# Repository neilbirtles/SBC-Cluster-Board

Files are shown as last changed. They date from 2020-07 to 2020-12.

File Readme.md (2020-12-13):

# SBC Cluster Board

## Overview

From many years of building Single Board Computer (SBC) Clusters and the pain to all the cables and configuration that goes with it came the idea to make a cluster board that didn't need lots of cables or a separate network switch to make it function. The SBC Cluster (SBC&#178;) Board is the embodiment of that idea.

The SBC&#178;Board will allow 5 SBC to be powered and networked over their USB-C connection. The SBC&#178; can provide up to 3.2A per port, with adjustable current limits to help limit damage in the event of any failures on the SBC themselves. Networking is provided through the use of USB gadget mode ethernet drivers that are standard in most Linux kernels.

Optional monitoring of the state of the SBC&#178; is achieved over an I2C connection to a host device. Configuration of the board is also possible over this link. A web frontend has been developed to make this a simple process without having to send arcane commands to specific registers on the I2C devices on the SBC&#178;.

The slots for SBC have been spaced so that a single 120mm fan can cool them all removing the noise of 5 smaller fans. The SBC&#178; provides a 12V step-up converter to power the fans from the proper voltage to ensure efficient cooling without the need for a second power supply.

A single 5v 100W power supply (e.g. LRS-100-5) is all that is needed to comfortably run 5 SBC meaning that the only cables required for the complete cluster are 1 mains cable to the power supply, 2 wires for +5v and 0V DC to the SBC&#178; and an optional 3 way cable to provide I2C comms back to a host device.

## SBC&#178; Components

There are a number of folders in this repository for the different components that make up the SBC&#178;. They are as follows:

##### PCB

This folder contains all the design files for the PCB, along with manufacturing information

##### Firmware

This folder contains the firmware that is flashed to the two microcontrollers that provide the control and monitoring functionality on the SBC&#178;

##### Frontend

This folder contains a Flask and Bootstrap based web frontend that can be run on one of the SBC in the cluster to provide information about and control over the SBC&#178;

##### Cases and Accessories

This folder contains the designs for the cases and accessories related to the SBC&#178;.

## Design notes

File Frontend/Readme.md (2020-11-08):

# Web Based Frontend for the SBC Cluster

This software is a Flask / Bootstrap based webserver that interfaces with the SBC Cluster board and provides easy access to allow monitoring and control of the cluster board.

This initial version provides monitoring of the supply voltage, current consumption and power for each of the slave boards and the ability to power cycle them. The ability to update the firmware in the cluster board is also provided. Future releases will provide the ability to set current limits for each SBC.

## Setup and Installation 

WiringPi-Python is required for communications with the hub board - for Khadas boards this can be installed by following the instructions here for Python 3 - https://github.com/khadas/WiringPi-Python#manual-build. Note that to get this working with Python 3 the pre-requisites required are as follows - sudo apt install python3-dev python3-setuptools swig

Setup the virtual environment to run this in with - the --system-site-packages allows access to WiringPi-Python 

`python3 -m venv venv --system-site-packages` 

Activate the virtual environment

`source venv/bin/activate`

Then install the required packages

`pip install -r requirements.txt`

Then run the webserver with

`python sbcclusterfrontend.py`

The webserver can then be accessed from the web browser of any machine on the same network at the IP address of the machine on port 5000, i.e. 192.0.0.2:5000

## Modifications for alternative SBC

The code as it stands will try and communicate with the USB hub board over the default device. On a Khadas VIM3 board this is '/dev/i2c-3' in the Khadas WiringPi-Python build, this will likely be different on different SBC. To change to a different device, e.g. '/dev/i2c-4', then change the two default setup lines `wiringpi.wiringPiI2CSetup(0x10)` and `wiringpi.wiringPiI2CSetup(0x11)` to `wiringpi.wiringPiI2CSetupInterface("/dev/i2c-4",0x10)` and `wiringpi.wiringPiI2CSetupInterface("/dev/i2c-4",0x10)` respectively. These changes need to be made in hubInterface.py

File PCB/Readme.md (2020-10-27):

# PCB Information

This is the PCB for the 5 way SBC Cluster Board. It has been produced in Eagle PCB.

## Manufacture Information

The PCBs have all been made by JLCPCB (https://jlcpcb.com/). The boards are 4 layer and must be made using controlled impedance due to the USB differential traces. The boards must be made 1.6mm thick and with the JLC controlled impedance process JLC7628

## Board Configuration

### Mains Power Measurement

There is provision on the board to use a current sensor IC to determine mains power usage for the system - this feature is mainly aimed at use in crypto currency applications where it is useful to know power consumption for the system to allow profitability to be calculated. If this function is not required then Resistor R44 is fitted to signal to the microcontroller that this function is not present on the board and J10, J11, IC7, C21 and C24 are not fitted.

### 12V DC Step-Up

The board also provides the ability to step up the incoming 5V supply to 12V to allow a standard PC fan to be powered without needing an additional power supply. The fan is connected via J8 and is the standard PC fan pinout. There is no speed control of the fan provided. If this is not required then components J8, D1, D2, C22, C23, R38, R39, IC8 and L1 are not fitted.

### Notes

IC5 can not be socketed otherwise it will foul the SBC plugged into J4. It must therefore be programmed and then soldered in

JP2 and JP3 are the programming headers for the microcontrollers on the board - they do not have to be fitted if pogo pins or similar are used to make contact for programming. Note that these headers are also used in the initial calibration (see firmware information) but the pads can be easily held low without the header fitted. 

JP4 provides the I2C bus out from the board and is set up to be a 3.3v bus with the relevant pull up resistors fitted to the board at R17 and R18 - these can be left off if the interfacing device already has pull up resistors in place. The pin-out for this is indicated on the PCB silk screen as 0-D-C for 0v, Data and Clock.

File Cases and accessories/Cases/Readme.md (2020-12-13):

# Cases

## Overview

To get the best cooling and easiest maintenance (especially prevention of dust build up) its a good idea to have a decent case for any cluster.

This folder contains the designs for cases that can be ordered from Protocase and will open in their free Protocase Designer software if you want to edit them.

## Cases

### 5 Way SBC Cluster Board Case.pda

This file contains the design for the 5 way case that is for sale on sbc-cluster.com. The case is designed to accommodate any standard 120mm fan at the rear and a 120mm dust filter at the front.

The case has mounting holes for a Meanwell LRS-75-5 power supply and an earth stud on each side of the case for safe earthing.

There is a hole cut for a snap in Bulgin Fused IEC connector for mains power inlet. The hole is sized for Bulgin part number PF0011/15/63.

Finally there is a mounting for a 5mm LED panel mount - Keystone part number 8310 will fit

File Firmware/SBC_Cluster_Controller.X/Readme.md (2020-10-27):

# SBC Cluster Controller Firmware

This firmware is used on the 5 port SBC Cluster Board. The same firmware is burnt to both the microcontrollers on the board, with configuration being set via pin strapping on the PCB.

The firmware is written in the MPLAB X IDE and uses the XC8 compiler

## Calibration

To use the voltage monitoring circuit the system must be calibrated against a known supply voltage. Once the firmware has been burnt to the microcontrollers then the calibration mode is entered by holding RB7 (pin 14) or Pin 4 of the programming header low at power on. The LED on the board will flash on /off every 100ms to indicate that it is ready for calibration, and the pin no longer has to be held low. The power supply can then be adjusted to exactly 5v. Once this has been done then the calibration is executed by taking RB6 (pin 13) or Pin 5 of the programming header low. The LED will flash 3 times at 500ms intervals to show that calibration is complete. This is a one time operation with the result stored in the non volatile memory of the microcontroller.

## Set offset for bootloader

This firmware is set up to be used with the I2C bootloader here https://github.com/neilbirtles/PIC16F1827_I2C_Bootloader. This allows for easy updating of controller firmware without a specific programmer. The project properties have been updated to start the cluster board firmware at an offset of 0x300. To use without the bootloader or with a different bootloader / offset then this can be change in Project Properties | XC8 Linker | Additional Options (in option categories) | Codeoffset 

## Memory Model Setup 

The linker will also tend to put a big gap in the middle of program memory starting at ~0x800 with some random RETLW instructions that aren't generated anywhere from the code around that address (they don't appear in the disassembly for instance, and can change the number of them with different code offset to move actual code closer / further from 0x800). Could not figure out what drove this behaviour in the linker but presumably something around management of memory pages, but it causes a problem for the bootloader because that tries to use the last address (0xFFF) in the controllers for its flag to show that a program is loaded and ready to run. The linkers approach puts program code over this location. The solution is to add the following "default,-FDF-FFF" in Project Properties | XC8 Linker | Memory Model (in option categories) | ROM Ranges. This stops the linker using the last 32 words of program memory. 32 words as PIC program memory can only be erased in complete rows (32 words for PIC16F1827), and so having this whole row blank makes for easier update (no read row, save state, erase row, change 0xFFF to the default 0x3FFF then re-write whole row, can just erase the row instead)

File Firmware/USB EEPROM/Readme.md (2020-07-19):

This is the bin file that needs to be burnt to the EEPROM that is used to configure the 2514 USB hub chip

The configuration can be viewed through the Microship Utility here:
http://ww1.microchip.com/downloads/en/DeviceDoc/e2promapp1020.msi

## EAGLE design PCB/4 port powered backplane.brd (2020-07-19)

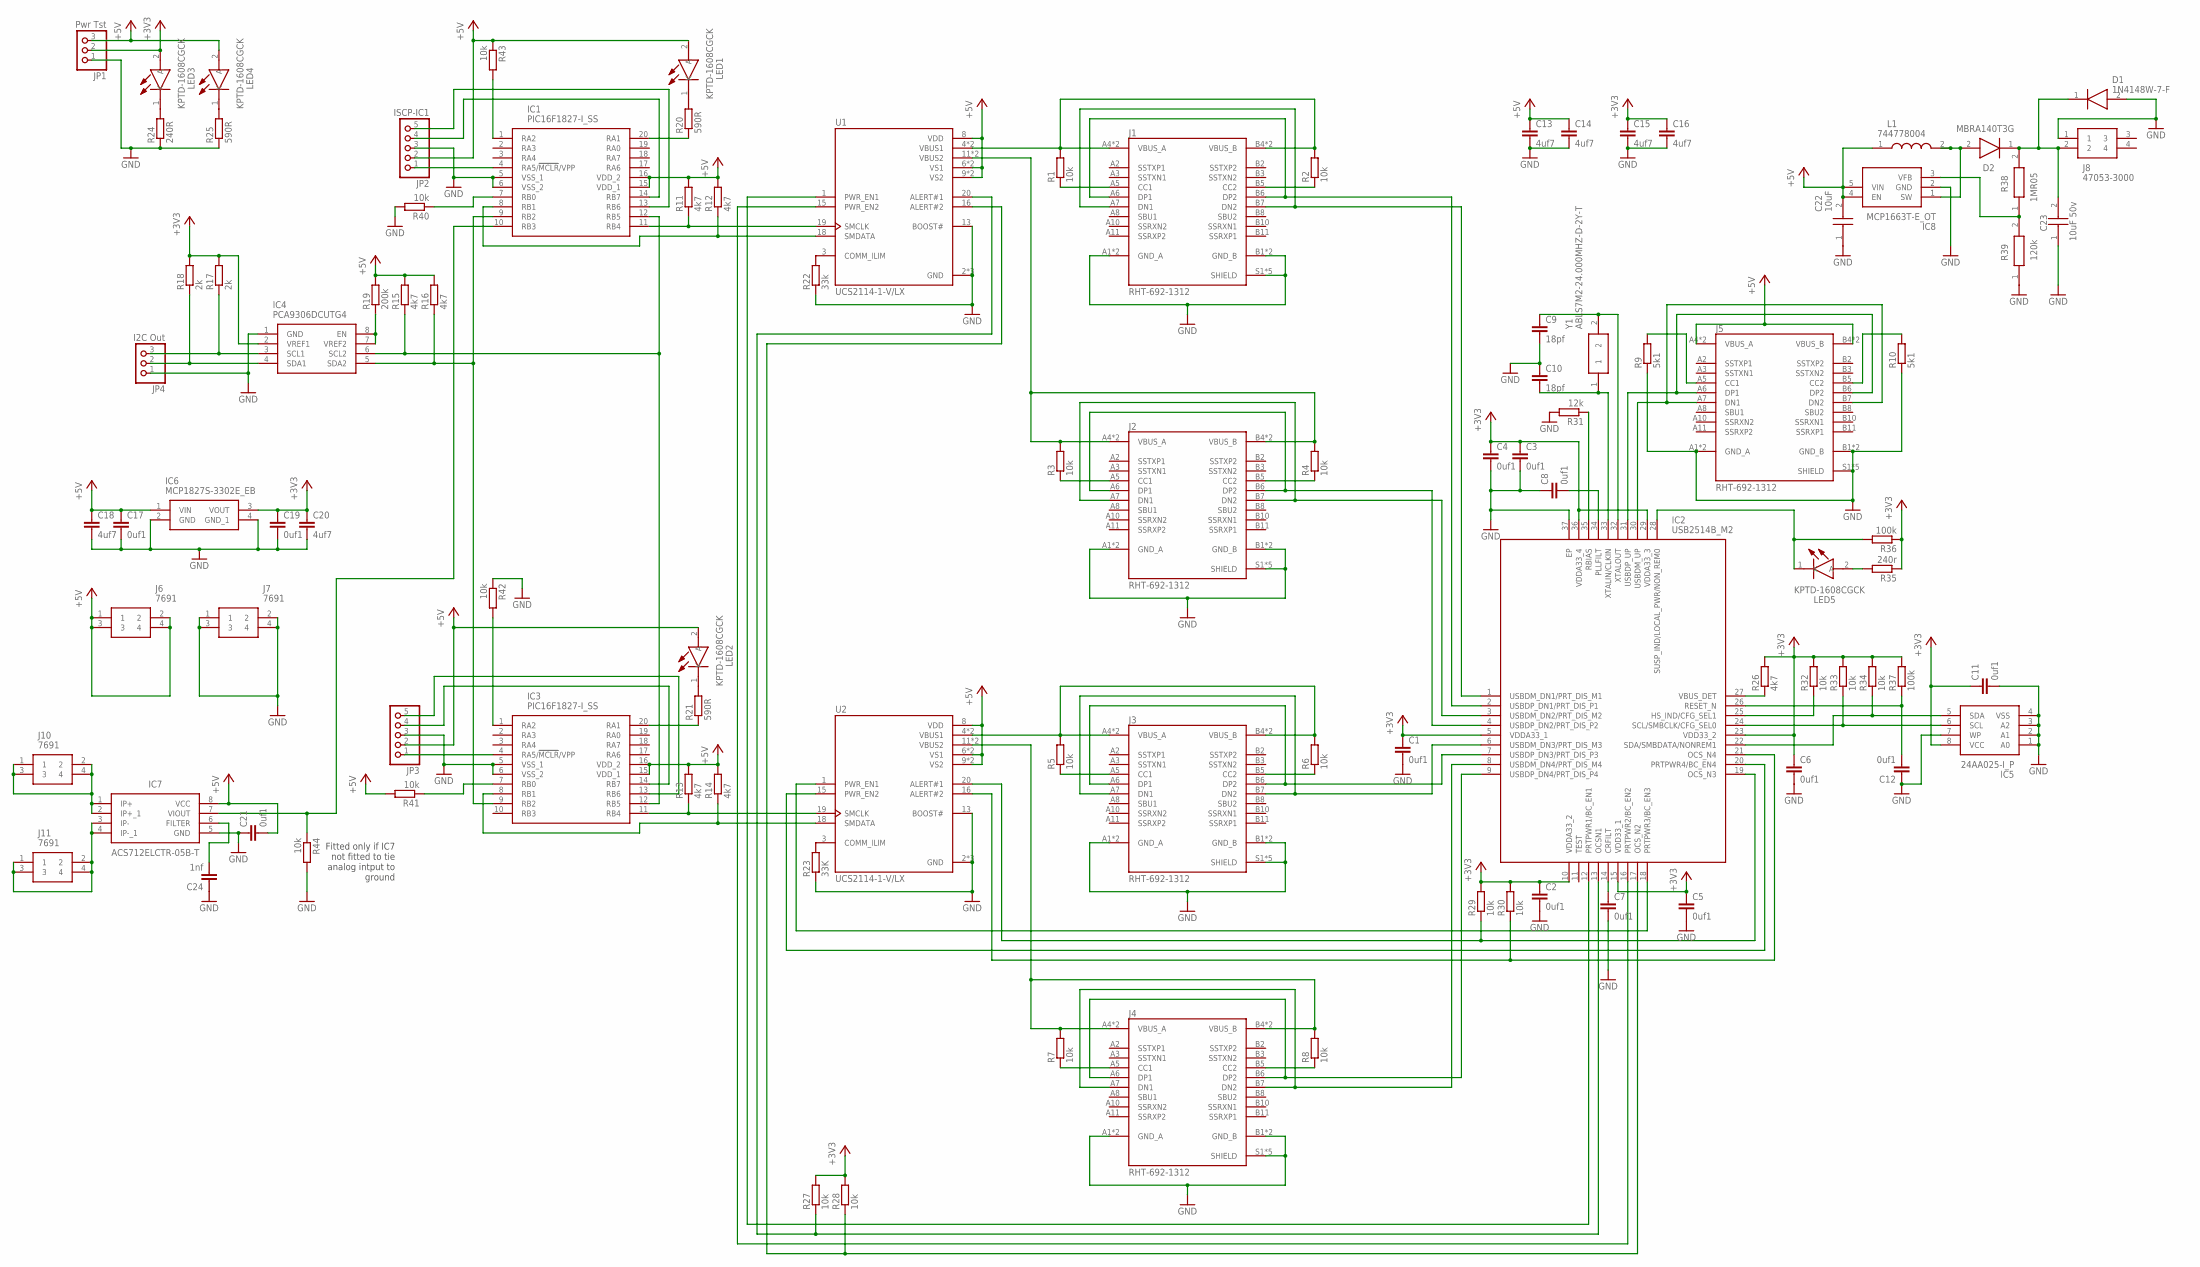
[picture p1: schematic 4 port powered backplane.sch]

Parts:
C1, C2, C3, C4, C5, C6, C7, C8, C11, C12, C17, C19, C21: 0uf1; C0603
C9, C10: 18pf; C0603
C13, C14, C15, C16, C18, C20: 4uf7; C0603
C22: 10uF; CAPC2012X145N
C23: 10uF 50v; CAPC3225X230N
C24: 1nf; C0603
D1: 1N4148W-7-F; SOD3716X115N
D2: MBRA140T3G; DIOM5226X220N
IC1, IC3: PIC16F1827-I_SS; SOP65P780X200-20N
IC2: USB2514B_M2; QFN50P600X600X100-37N
IC4: PCA9306DCUTG4; SOP50P310X90-8N
IC5: 24AA025-I_P; DIP781W56P254L950H533Q8N
IC6: MCP1827S-3302E_EB; TO254P1491X508-4N
IC7: ACS712ELCTR-05B-T; SOIC127P600X175-8N
IC8: MCP1663T-E_OT; SOT95P270X145-5N
J1, J2, J3, J4, J5: RHT-692-1312; RENHOTEC_RHT-692-1312
J6, J7, J10, J11: 7691
J8: 47053-3000; 470533000
JP1: Pwr Tst; 1X03
JP2: ISCP-IC1; 1X05
JP3: PINHD-1X5; 1X05
JP4: I2C Out; 1X03
L1: 744778004
LED1, LED2, LED3, LED4, LED5: KPTD-1608CGCK; LEDC1608X85N
R1, R2, R3, R4, R5, R6, R7, R8, R27, R28, R29, R30, R32, R33, R34, R40, R41, R42, R43, R44: 10k; R0603
R9, R10: 5k1; R0603
R11, R12, R13, R14, R15, R16, R26: 4k7; R0603
R17, R18: 2k; R0603
R19: 200k; R0603
R20, R21, R25: 590R; R0603
R22: 33k; R0603
R23: 33K; R0603
R24: 240R; R0603
R31: 12k; R0603
R35: 240r; R0603
R36, R37: 100k; R0603
R38: 1MR05; RESC2012X70N
R39: 120k; RESC2012X70N
U1, U2: UCS2114-1-V/LX; IC_UCS2114-1-V/LX
Y1: ABLS7M2-24.000MHZ-D-2Y-T; ABLS7M2

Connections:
+3V3: C1.1, C2.1, C3.1, C4.1, C5.1, C6.1, C11.1, C15.1, C16.1, C19.1, C20.1, IC2.5 (VDDA33_1), IC2.10 (VDDA33_2), IC2.15 (VDD33_1), IC2.23 (VDD33_2), IC2.29 (VDDA33_3), IC2.36 (VDDA33_4), IC4.2 (VREF1), IC5.8 (VCC), IC6.3 (VOUT), JP1.2, LED3.2 (A), R17.2, R18.2, R26.2, R27.2, R28.2, R29.2, R30.2, R32.2, R33.2, R34.2, R35.1, R36.1, R37.2
+5V: C13.1, C14.1, C17.1, C18.1, C21.2, C22.2, IC1.15 (VDD_1), IC1.16 (VDD_2), IC3.15 (VDD_1), IC3.16 (VDD_2), IC6.1 (VIN), IC7.8 (VCC), IC8.4 (EN), IC8.5 (VIN), J5.A4 (VBUS_A), J5.A9 (VBUS_A), J5.B4 (VBUS_B), J5.B9 (VBUS_B), J6.1, J6.2, J6.3, J6.4, JP1.3, JP2.2, JP3.2, L1.1, LED1.2 (A), LED2.2 (A), LED4.2 (A), R11.2, R12.2, R13.2, R14.2, R15.2, R16.2, R19.2, R41.2, R43.1, U1.6 (VS1), U1.7 (VS1), U1.8 (VDD), U1.9 (VS2), U1.10 (VS2), U2.6 (VS1), U2.7 (VS1), U2.8 (VDD), U2.9 (VS2), U2.10 (VS2)
DOWN1_N: IC2.1 (USBDM_DN1/PRT_DIS_M1), J1.A7 (DN1), J1.B7 (DN2)
DOWN1_P: IC2.2 (USBDP_DN1/PRT_DIS_P1), J1.A6 (DP1), J1.B6 (DP2)
DOWN2_N: IC2.3 (USBDM_DN2/PRT_DIS_M2), J2.A7 (DN1), J2.B7 (DN2)
DOWN2_P: IC2.4 (USBDP_DN2/PRT_DIS_P2), J2.A6 (DP1), J2.B6 (DP2)
DOWN3_N: IC2.6 (USBDM_DN3/PRT_DIS_M3), J3.A7 (DN1), J3.B7 (DN2)
DOWN3_P: IC2.7 (USBDP_DN3/PRT_DIS_P3), J3.A6 (DP1), J3.B6 (DP2)
DOWN4_N: IC2.8 (USBDM_DN4/PRT_DIS_M4), J4.A7 (DN1), J4.B7 (DN2)
DOWN4_P: IC2.9 (USBDP_DN4/PRT_DIS_P4), J4.A6 (DP1), J4.B6 (DP2)
GND: C1.2, C2.2, C3.2, C4.2, C5.2, C6.2, C7.2, C8.1, C9.2, C10.1, C11.2, C12.1, C13.2, C14.2, C15.2, C16.2, C17.2, C18.2, C19.2, C20.2, C21.1, C22.1, C23.1, C24.1, D1.2 (A), IC1.5 (VSS_1), IC1.6 (VSS_2), IC2.37 (EP), IC3.5 (VSS_1), IC3.6 (VSS_2), IC4.1 (GND), IC5.1 (A0), IC5.2 (A1), IC5.3 (A2), IC5.4 (VSS), IC5.7 (WP), IC6.2 (GND), IC6.4 (GND_1), IC7.5 (GND), IC8.2 (GND), J1.A1 (GND_A), J1.A12 (GND_A), J1.B1 (GND_B), J1.B12 (GND_B), J1.S1 (SHIELD), J1.S2 (SHIELD), J1.S3 (SHIELD), J1.S4 (SHIELD), J1.S5 (SHIELD), J2.A1 (GND_A), J2.A12 (GND_A), J2.B1 (GND_B), J2.B12 (GND_B), J2.S1 (SHIELD), J2.S2 (SHIELD), J2.S3 (SHIELD), J2.S4 (SHIELD), J2.S5 (SHIELD), J3.A1 (GND_A), J3.A12 (GND_A), J3.B1 (GND_B), J3.B12 (GND_B), J3.S1 (SHIELD), J3.S2 (SHIELD), J3.S3 (SHIELD), J3.S4 (SHIELD), J3.S5 (SHIELD), J4.A1 (GND_A), J4.A12 (GND_A), J4.B1 (GND_B), J4.B12 (GND_B), J4.S1 (SHIELD), J4.S2 (SHIELD), J4.S3 (SHIELD), J4.S4 (SHIELD), J4.S5 (SHIELD), J5.A1 (GND_A), J5.A12 (GND_A), J5.B1 (GND_B), J5.B12 (GND_B), J5.S1 (SHIELD), J5.S2 (SHIELD), J5.S3 (SHIELD), J5.S4 (SHIELD), J5.S5 (SHIELD), J7.1, J7.2, J7.3, J7.4, J8.1, JP1.1, JP2.3, JP3.3, JP4.1, R9.1, R10.1, R22.1, R23.1, R24.1, R25.1, R31.2, R39.1, R40.2, R42.1, R44.2, U1.2 (GND), U1.13 (BOOST#), U1.14 (GND), U1.17 (GND), U2.2 (GND), U2.13 (BOOST#), U2.14 (GND), U2.17 (GND)
unnamed: IC1.10 (RB3), IC7.7 (VIOUT), R44.1
unnamed: D2.2 (A), IC8.1 (SW), L1.2
unnamed: C23.2, D1.1 (K), D2.1 (K), J8.2, R38.2
unnamed: IC8.3 (VFB), R38.1, R39.2
unnamed: C24.2, IC7.6 (FILTER)
unnamed: IC1.7 (RB0), R40.1
unnamed: IC3.7 (RB0), R41.1
unnamed: IC3.1 (RA2), R42.2
unnamed: IC1.1 (RA2), R43.2
unnamed: J5.A5 (CC1), R9.2
unnamed: J5.B5 (CC2), R10.2
unnamed: IC1.11 (RB4), R11.1, U1.19 (SMCLK)
unnamed: IC2.27 (VBUS_DET), R26.1
unnamed: J2.A5 (CC1), R3.1
unnamed: J2.B5 (CC2), R4.1
unnamed: J1.A5 (CC1), R1.1
unnamed: J1.B5 (CC2), R2.1
unnamed: J4.A5 (CC1), R7.1
unnamed: J4.B5 (CC2), R8.1
unnamed: J1.A4 (VBUS_A), J1.A9 (VBUS_A), J1.B4 (VBUS_B), J1.B9 (VBUS_B), R1.2, R2.2, U1.4 (VBUS1), U1.5 (VBUS1)
unnamed: J2.A4 (VBUS_A), J2.A9 (VBUS_A), J2.B4 (VBUS_B), J2.B9 (VBUS_B), R3.2, R4.2, U1.11 (VBUS2), U1.12 (VBUS2)
unnamed: J3.A5 (CC1), R5.1
unnamed: J3.B5 (CC2), R6.1
unnamed: IC2.13 (OCSN1), R27.1, U1.20 (ALERT#1)
unnamed: IC2.12 (PRTPWR1/BC_EN1), U1.1 (PWR_EN1)
unnamed: IC2.16 (PRTPWR2/BC_EN2), U1.15 (PWR_EN2)
unnamed: IC2.17 (OCS_N2), R28.1, U1.16 (ALERT#2)
unnamed: IC2.18 (PRTPWR3/BC_EN3), U2.1 (PWR_EN1)
unnamed: IC2.20 (PRTPWR4/BC_EN4), U2.15 (PWR_EN2)
unnamed: IC2.19 (OCS_N3), R29.1, U2.20 (ALERT#1)
unnamed: IC2.21 (OCS_N4), R30.1, U2.16 (ALERT#2)
unnamed: IC3.11 (RB4), R13.1, U2.19 (SMCLK)
unnamed: IC3.8 (RB1), R14.1, U2.18 (SMDATA)
unnamed: IC1.9 (RB2), IC3.9 (RB2), IC4.5 (SDA2), R16.1
unnamed: IC1.12 (RB5), IC3.12 (RB5), IC4.6 (SCL2), R15.1
unnamed: C7.1, IC2.14 (CRFILT)
unnamed: IC1.8 (RB1), R12.1, U1.18 (SMDATA)
unnamed: IC1.4 (RA5/!MCLR!/VPP), JP2.1
unnamed: IC4.7 (VREF2), IC4.8 (EN), R19.1
unnamed: IC4.3 (SCL1), JP4.3, R17.1
unnamed: IC4.4 (SDA1), JP4.2, R18.1
unnamed: IC3.4 (RA5/!MCLR!/VPP), JP3.1
unnamed: IC1.14 (RB7), JP2.4
unnamed: IC1.13 (RB6), JP2.5
unnamed: IC3.14 (RB7), JP3.4
unnamed: IC3.13 (RB6), JP3.5
unnamed: IC1.20 (RA1), R20.1
unnamed: IC3.20 (RA1), R21.1
unnamed: LED1.1 (K), R20.2
unnamed: LED2.1 (K), R21.2
unnamed: R22.2, U1.3 (COMM_ILIM)
unnamed: R23.2, U2.3 (COMM_ILIM)
unnamed: LED3.1 (K), R24.2
unnamed: LED4.1 (K), R25.2
unnamed: C8.2, IC2.34 (PLLFILT)
unnamed: C10.2, IC2.33 (XTALIN/CLKIN), Y1.1
unnamed: C9.1, IC2.32 (XTALOUT), Y1.2
unnamed: IC2.24 (SCL/SMBCLK/CFG_SEL0), IC5.6 (SCL), R33.1
unnamed: IC2.22 (SDA/SMBDATA/NONREM1), IC5.5 (SDA), R34.1
unnamed: IC2.35 (RBIAS), R31.1
unnamed: IC2.25 (HS_IND/CFG_SEL1), R32.1
unnamed: LED5.2 (A), R35.2
unnamed: IC2.28 (SUSP_IND/LOCAL_PWR/NON_REM0), LED5.1 (K), R36.2
unnamed: C12.2, IC2.26 (RESET_N), R37.1
unnamed: IC7.3 (IP-), IC7.4 (IP-_1), J11.1, J11.2, J11.3, J11.4
unnamed: IC7.1 (IP+), IC7.2 (IP+_1), J10.1, J10.2, J10.3, J10.4
PWR3: J3.A4 (VBUS_A), J3.A9 (VBUS_A), J3.B4 (VBUS_B), J3.B9 (VBUS_B), R5.2, R6.2, U2.4 (VBUS1), U2.5 (VBUS1)
PWR4: J4.A4 (VBUS_A), J4.A9 (VBUS_A), J4.B4 (VBUS_B), J4.B9 (VBUS_B), R7.2, R8.2, U2.11 (VBUS2), U2.12 (VBUS2)
UP_N: IC2.30 (USBDM_UP), J5.A7 (DN1), J5.B7 (DN2)
UP_P: IC2.31 (USBDP_UP), J5.A6 (DP1), J5.B6 (DP2)

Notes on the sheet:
Fitted only if IC7 not fitted to tie analog intput to ground

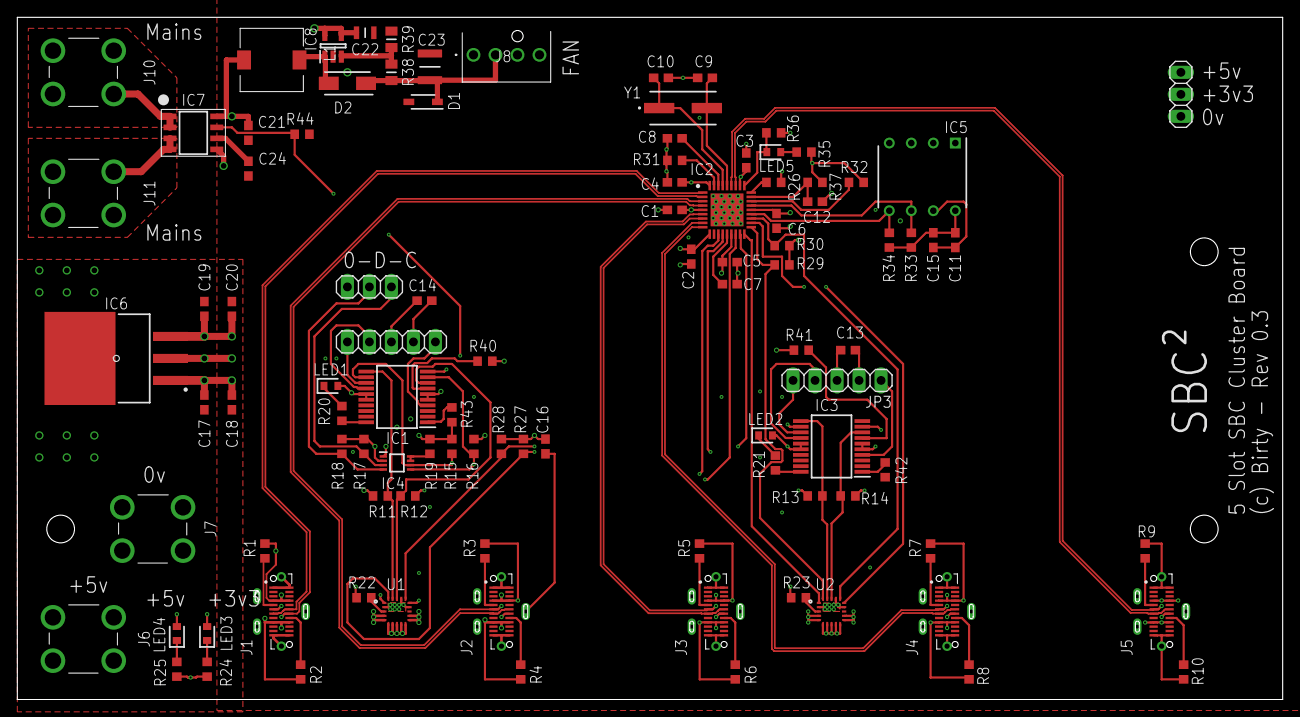
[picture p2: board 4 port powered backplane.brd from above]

Board: 4 copper layers, 146.0 x 78.7 mm, 101 parts (0 on the bottom side), 81 nets.

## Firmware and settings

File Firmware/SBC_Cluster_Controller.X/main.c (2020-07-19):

/**
  Company:
    Birty

  File Name:
    main.c

  Summary:
    

  Description:
    
*/

#include "mcc_generated_files/mcc.h"
#include "main.h"
#include "I2C_Slave_Interrupt_Handlers.h"
#include "I2C_Master.h"
#include "UCS2114_Driver.h"

/*
 * \brief stores the result of an ADC conversion so that can get at the bytes
 * easily
 */
typedef union adc_value_pair
{
    uint16_t value16;
    uint8_t values8[2];
}adc_value;

adc_value calibration_value;
uint16_t voltage_cal_stage_1 = 0;

//values to use match the calibration voltage applied * 100 i.e. 5v
const uint16_t volt_cal_ref = 500;
//formula for measuring VDD always divides this number by 2 so do it here
//to save maths later 
const uint16_t volt_cal_ref_corrected = volt_cal_ref / 2;

//EEPROM addresses for storing the voltage cal information
const uint8_t voltage_cal_low_addr = 0x00;
const uint8_t voltage_cal_high_addr = 0x01;

/*
                         Main application
 */


void delay_10ms_multiple(uint8_t multiple)
{
    int i;
    for (i = 0; i < multiple; i++) {
        __delay_ms(10);
    }
}

uint16_t measure_vdd()
{
    uint16_t adc_result = 0;
    uint16_t stage2 = 0;
    
    //wait for the FVR to be ready
    while(!FVR_IsOutputReady()){}
    //measure VDD against the FVR
    adc_result = ADC_GetConversion(channel_FVR);
    
    /* TAKEN FROM MICROCHIP APP NOTE 1072 - calibrate the reading
     1) Multiply  VREFCORRECTED * VP6CALVAL 
	 2) Divide 16-bit result 1) by 16-bit reading of ADC unknown voltage
	 3) Multiply 16-bit result by 2 (shift left once)
     */
    
    //stage 1) done when the calibration is changed or loaded
    
    //stage 2)   
    stage2 = voltage_cal_stage_1 / adc_result;
    
    //stage 3)
    return stage2 << 1;
}

bool check_for_voltage_cal(void)
{
    //pin 4 of prog header low to enter
    if (!Enter_Voltage_Cal_GetValue()) 
    {
        //voltage calibration mode has been asked for
        //wait until voltage cal start is flagged
        //pin 5 of prog header low to start
        while(Start_Voltage_Cal_GetValue())
        {
            LED_Toggle();
            __delay_ms(100);
        }
        LED_SetLow();
        
        //entered voltage calibration
        //wait for FVR to be ready
        while(!FVR_IsOutputReady()){}
        //get the count value against a known Vdd and the 1.024v ref
        calibration_value.value16 = ADC_GetConversion(channel_FVR);
        //store these values in EEPROM
        eeprom_write(voltage_cal_high_addr, calibration_value.values8[1]);
        eeprom_write(voltage_cal_low_addr, calibration_value.values8[0]); 
        
        voltage_cal_stage_1 = volt_cal_ref_corrected * calibration_value.value16;
        
        //did a voltage calibration show that via LED
        LED_Toggle();
        __delay_ms(500);
        LED_Toggle();
        __delay_ms(500);
        LED_Toggle();
        __delay_ms(500);
        LED_Toggle();
        __delay_ms(500);
        LED_Toggle();
        __delay_ms(500);
        LED_Toggle();
        __delay_ms(500);
        LED_Toggle();
               
        return true;
    }else 
    {
        //didnt do a voltage calibration
        return false;
    }
}

void load_voltage_cal(void)
{
    calibration_value.values8[1] = eeprom_read(voltage_cal_high_addr);
    calibration_value.values8[0] = eeprom_read(voltage_cal_low_addr);
    
    voltage_cal_stage_1 = volt_cal_ref_corrected * calibration_value.value16;
}

void main(void)
{
    // initialize the device
    SYSTEM_Initialize();
    
    //do voltage calibration or load in existing values 
    calibration_value.value16 = 0;
    if (!check_for_voltage_cal())
    {
        //didnt do a voltage calibration so need to load the old values 
        load_voltage_cal();
    }
    
    //open up the I2C slave
    I2C2_Open();
    I2C2_SlaveSetWriteIntHandler(I2C_SlaveWriteInterruptHandler);
    I2C2_SlaveSetReadIntHandler(I2C_SlaveReadInterruptHandler);
    I2C2_SlaveSetAddrIntHandler(I2C_SlaveAddressInterruptHandler);
    //work out the address for this slave based on the state of address pin
    //left shift as only 7 MSB used in SSP2ADD
    if(I2C_Addr_Bit_GetValue())
    {
        SSP2ADD = 0x11 << 1;
    }else
    {
        SSP2ADD = 0x10 << 1;
    }
    
    
    // When using interrupts, you need to set the Global and Peripheral Interrupt Enable bits
    // Use the following macros to:

    // Enable the Global Interrupts
    INTERRUPT_GlobalInterruptEnable();

    // Enable the Peripheral Interrupts
    INTERRUPT_PeripheralInterruptEnable();

    // Disable the Global Interrupts
    //INTERRUPT_GlobalInterruptDisable();

    // Disable the Peripheral Interrupts
    //INTERRUPT_PeripheralInterruptDisable();

    while (1)
    {
        // Add your application code
        delay_10ms_multiple(g_flash_freq);
        LED_Toggle();
        
        //read all the info from the port controller
        g_port_controller_data[ucs2114_port1][ucs2114_current_measurement] = UCS2114_get_port_one_current();
        g_port_controller_data[ucs2114_port2][ucs2114_current_measurement] = UCS2114_get_port_two_current();
                
        g_port_controller_data[ucs2114_port1][ucs2114_port_status] = UCS2114_get_port_status_reg().byte_val;
        //port 1 and port 2 share this port status register 
        g_port_controller_data[ucs2114_port2][ucs2114_port_status] = g_port_controller_data[ucs2114_port1][ucs2114_port_status];
        
        //dont get the interrupt registers as getting them clears the status 
        //g_port_controller_data[port1][interrupt_status] = UCS2114_get_interrupt_status_1_reg().byte_val;
        //g_port_controller_data[port2][interrupt_status] = UCS2114_get_interrupt_status_2_reg().byte_val;
                
        g_port_controller_data[ucs2114_port1][ucs2114_general_status] = UCS2114_get_general_status_1_reg().byte_val;
        g_port_controller_data[ucs2114_port2][ucs2114_general_status] = UCS2114_get_general_status_2_reg().byte_val;

        adc_value adc_reading;
        //mains current read and store
        adc_reading.value16 = ADC_GetConversion(Mains_Current_Sensor);
        g_port_controller_data[controller_general][mains_current_msb] = adc_reading.values8[1];
        g_port_controller_data[controller_general][mains_current_lsb] = adc_reading.values8[0];
        
        //supply voltage read and store
        adc_reading.value16 = measure_vdd();
        g_port_controller_data[controller_general][supply_voltage_msb] = adc_reading.values8[1];
        g_port_controller_data[controller_general][supply_voltage_lsb] = adc_reading.values8[0];
    }
}
/**
 End of File
*/

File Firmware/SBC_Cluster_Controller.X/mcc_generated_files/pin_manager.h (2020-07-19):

/**
  @Generated Pin Manager Header File

  @Company:
    Microchip Technology Inc.

  @File Name:
    pin_manager.h

  @Summary:
    This is the Pin Manager file generated using PIC10 / PIC12 / PIC16 / PIC18 MCUs

  @Description
    This header file provides APIs for driver for .
    Generation Information :
        Product Revision  :  PIC10 / PIC12 / PIC16 / PIC18 MCUs - 1.81.0
        Device            :  PIC16F1827
        Driver Version    :  2.11
    The generated drivers are tested against the following:
        Compiler          :  XC8 2.10 and above
        MPLAB 	          :  MPLAB X 5.35	
*/

/*
    (c) 2018 Microchip Technology Inc. and its subsidiaries. 
    
    Subject to your compliance with these terms, you may use Microchip software and any 
    derivatives exclusively with Microchip products. It is your responsibility to comply with third party 
    license terms applicable to your use of third party software (including open source software) that 
    may accompany Microchip software.
    
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
    IN NO EVENT WILL MICROCHIP BE LIABLE FOR ANY INDIRECT, SPECIAL, PUNITIVE, 
    INCIDENTAL OR CONSEQUENTIAL LOSS, DAMAGE, COST OR EXPENSE OF ANY KIND 
    WHATSOEVER RELATED TO THE SOFTWARE, HOWEVER CAUSED, EVEN IF MICROCHIP 
    HAS BEEN ADVISED OF THE POSSIBILITY OR THE DAMAGES ARE FORESEEABLE. TO 
    THE FULLEST EXTENT ALLOWED BY LAW, MICROCHIP'S TOTAL LIABILITY ON ALL 
    CLAIMS IN ANY WAY RELATED TO THIS SOFTWARE WILL NOT EXCEED THE AMOUNT 
    OF FEES, IF ANY, THAT YOU HAVE PAID DIRECTLY TO MICROCHIP FOR THIS 
    SOFTWARE.
*/

#ifndef PIN_MANAGER_H
#define PIN_MANAGER_H

/**
  Section: Included Files
*/

#include <xc.h>

#define INPUT   1
#define OUTPUT  0

#define HIGH    1
#define LOW     0

#define ANALOG      1
#define DIGITAL     0

#define PULL_UP_ENABLED      1
#define PULL_UP_DISABLED     0

// get/set LED aliases
#define LED_TRIS                 TRISAbits.TRISA1
#define LED_LAT                  LATAbits.LATA1
#define LED_PORT                 PORTAbits.RA1
#define LED_ANS                  ANSELAbits.ANSA1
#define LED_SetHigh()            do { LATAbits.LATA1 = 1; } while(0)
#define LED_SetLow()             do { LATAbits.LATA1 = 0; } while(0)
#define LED_Toggle()             do { LATAbits.LATA1 = ~LATAbits.LATA1; } while(0)
#define LED_GetValue()           PORTAbits.RA1
#define LED_SetDigitalInput()    do { TRISAbits.TRISA1 = 1; } while(0)
#define LED_SetDigitalOutput()   do { TRISAbits.TRISA1 = 0; } while(0)
#define LED_SetAnalogMode()      do { ANSELAbits.ANSA1 = 1; } while(0)
#define LED_SetDigitalMode()     do { ANSELAbits.ANSA1 = 0; } while(0)

// get/set Has_Mains_Current_Sensor aliases
#define Has_Mains_Current_Sensor_TRIS                 TRISAbits.TRISA2
#define Has_Mains_Current_Sensor_LAT                  LATAbits.LATA2
#define Has_Mains_Current_Sensor_PORT                 PORTAbits.RA2
#define Has_Mains_Current_Sensor_ANS                  ANSELAbits.ANSA2
#define Has_Mains_Current_Sensor_SetHigh()            do { LATAbits.LATA2 = 1; } while(0)
#define Has_Mains_Current_Sensor_SetLow()             do { LATAbits.LATA2 = 0; } while(0)
#define Has_Mains_Current_Sensor_Toggle()             do { LATAbits.LATA2 = ~LATAbits.LATA2; } while(0)
#define Has_Mains_Current_Sensor_GetValue()           PORTAbits.RA2
#define Has_Mains_Current_Sensor_SetDigitalInput()    do { TRISAbits.TRISA2 = 1; } while(0)
#define Has_Mains_Current_Sensor_SetDigitalOutput()   do { TRISAbits.TRISA2 = 0; } while(0)
#define Has_Mains_Current_Sensor_SetAnalogMode()      do { ANSELAbits.ANSA2 = 1; } while(0)
#define Has_Mains_Current_Sensor_SetDigitalMode()     do { ANSELAbits.ANSA2 = 0; } while(0)

// get/set I2C_Addr_Bit aliases
#define I2C_Addr_Bit_TRIS                 TRISBbits.TRISB0
#define I2C_Addr_Bit_LAT                  LATBbits.LATB0
#define I2C_Addr_Bit_PORT                 PORTBbits.RB0
#define I2C_Addr_Bit_WPU                  WPUBbits.WPUB0
#define I2C_Addr_Bit_SetHigh()            do { LATBbits.LATB0 = 1; } while(0)
#define I2C_Addr_Bit_SetLow()             do { LATBbits.LATB0 = 0; } while(0)
#define I2C_Addr_Bit_Toggle()             do { LATBbits.LATB0 = ~LATBbits.LATB0; } while(0)
#define I2C_Addr_Bit_GetValue()           PORTBbits.RB0
#define I2C_Addr_Bit_SetDigitalInput()    do { TRISBbits.TRISB0 = 1; } while(0)
#define I2C_Addr_Bit_SetDigitalOutput()   do { TRISBbits.TRISB0 = 0; } while(0)
#define I2C_Addr_Bit_SetPullup()          do { WPUBbits.WPUB0 = 1; } while(0)
#define I2C_Addr_Bit_ResetPullup()        do { WPUBbits.WPUB0 = 0; } while(0)

// get/set RB1 procedures
#define RB1_SetHigh()            do { LATBbits.LATB1 = 1; } while(0)
#define RB1_SetLow()             do { LATBbits.LATB1 = 0; } while(0)
#define RB1_Toggle()             do { LATBbits.LATB1 = ~LATBbits.LATB1; } while(0)
#define RB1_GetValue()              PORTBbits.RB1
#define RB1_SetDigitalInput()    do { TRISBbits.TRISB1 = 1; } while(0)
#define RB1_SetDigitalOutput()   do { TRISBbits.TRISB1 = 0; } while(0)
#define RB1_SetPullup()             do { WPUBbits.WPUB1 = 1; } while(0)
#define RB1_ResetPullup()           do { WPUBbits.WPUB1 = 0; } while(0)
#define RB1_SetAnalogMode()         do { ANSELBbits.ANSB1 = 1; } while(0)
#define RB1_SetDigitalMode()        do { ANSELBbits.ANSB1 = 0; } while(0)

// get/set RB2 procedures
#define RB2_SetHigh()            do { LATBbits.LATB2 = 1; } while(0)
#define RB2_SetLow()             do { LATBbits.LATB2 = 0; } while(0)
#define RB2_Toggle()             do { LATBbits.LATB2 = ~LATBbits.LATB2; } while(0)
#define RB2_GetValue()              PORTBbits.RB2
#define RB2_SetDigitalInput()    do { TRISBbits.TRISB2 = 1; } while(0)
#define RB2_SetDigitalOutput()   do { TRISBbits.TRISB2 = 0; } while(0)
#define RB2_SetPullup()             do { WPUBbits.WPUB2 = 1; } while(0)
#define RB2_ResetPullup()           do { WPUBbits.WPUB2 = 0; } while(0)
#define RB2_SetAnalogMode()         do { ANSELBbits.ANSB2 = 1; } while(0)
#define RB2_SetDigitalMode()        do { ANSELBbits.ANSB2 = 0; } while(0)
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

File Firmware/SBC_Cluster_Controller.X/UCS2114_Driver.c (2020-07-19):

/*
 * File:   UCS2114_Driver.c
 * Author: neilb
 *
 * Created on April 26, 2020, 8:33 AM
 */

/**
  Section: Included Files
*/
#include <xc.h>
#include "UCS2114_Driver.h"
#include "I2C_Master.h"

//used to map to the UCS2114 registers
static UCS2114_REGISTER genConfig1, genConfig2, genConfig3, iLimBehP1, iLimBehP2;


void UCS2114setPWR_ENpinsIgnore(void)
{
    genConfig3.general_configuration3_bits.pin_ign = 1;
    
    I2C_master_write_one_byte_register(UCS2114_ADDRESS, 
           UCS2114_REG_GENERAL_CONFIGURATION3, genConfig3.byte_val); 
}


void UCS2114clearPWR_ENpinsIgnore(void)
{
    genConfig3.general_configuration3_bits.pin_ign = 0;
    
    I2C_master_write_one_byte_register(UCS2114_ADDRESS, 
           UCS2114_REG_GENERAL_CONFIGURATION3, genConfig3.byte_val);    
}


void UCS2114setPWR_EN1bit(void)
{
    genConfig1.general_configuration1_bits.pwr_en1s = 1;
    
    I2C_master_write_one_byte_register(UCS2114_ADDRESS, 
           UCS2114_REG_GENERAL_CONFIGURATION1, genConfig1.byte_val);
}

void UCS2114clearPWR_EN1bit(void)
{
   genConfig1.general_configuration1_bits.pwr_en1s = 0;
    
    I2C_master_write_one_byte_register(UCS2114_ADDRESS, 
           UCS2114_REG_GENERAL_CONFIGURATION1, genConfig1.byte_val);    
}


void UCS2114setPWR_EN2bit(void)
{
    genConfig2.general_configuration2_bits.pwr_en2s = 1;
    
    I2C_master_write_one_byte_register(UCS2114_ADDRESS, 
           UCS2114_REG_GENERAL_CONFIGURATION2, genConfig2.byte_val);
}

void UCS2114clearPWR_EN2bit(void)
{
    genConfig2.general_configuration2_bits.pwr_en2s = 0;
    
    I2C_master_write_one_byte_register(UCS2114_ADDRESS, 
           UCS2114_REG_GENERAL_CONFIGURATION2, genConfig2.byte_val);    
}

void UCS2114setCurrentLimit(uint8_t i_lim_port_1, uint8_t i_lim_port_2)
{
    uint8_t limit_reg_content=0x00;
    
    //max values for limit is 7 - 0b111
    if (i_lim_port_1 > 7) i_lim_port_1 = 7;
    if (i_lim_port_2 > 7) i_lim_port_2 = 7;
    
    //limit register has:
    //bit<5:3> port 1 limit
    //bit<2:0> port 2 limit
    //so get everything in the right place
    limit_reg_content = i_lim_port_1;
    limit_reg_content <<= 3;
    limit_reg_content += i_lim_port_2;
    
    I2C_master_write_one_byte_register(UCS2114_ADDRESS, 
           UCS2114_REG_CURRENT_LIMIT, limit_reg_content);
}


void UCS2114setDISCHG_LOAD1bit(void)
{
    iLimBehP1.port1_current_limit_behavior_bits.dischg_load1 = 1;
    
    I2C_master_write_one_byte_register(UCS2114_ADDRESS, 
           UCS2114_REG_PORT1_CURRENT_LIMIT_BEHAVIOR, iLimBehP1.byte_val);
}


void UCS2114clearDISCHG_LOAD1bit(void)
{
iLimBehP1.port1_current_limit_behavior_bits.dischg_load1 = 0;
    
    I2C_master_write_one_byte_register(UCS2114_ADDRESS, 
           UCS2114_REG_PORT1_CURRENT_LIMIT_BEHAVIOR, iLimBehP1.byte_val);    
}


void UCS2114setDISCHG_LOAD2bit(void)
{
    iLimBehP2.port2_current_limit_behavior_bits.dischg_load2 = 1;
    
    I2C_master_write_one_byte_register(UCS2114_ADDRESS, 
           UCS2114_REG_PORT2_CURRENT_LIMIT_BEHAVIOR, iLimBehP2.byte_val);    
}


void UCS2114clearDISCHG_LOAD2bit(void)
{
    iLimBehP2.port2_current_limit_behavior_bits.dischg_load2 = 0;
    
    I2C_master_write_one_byte_register(UCS2114_ADDRESS, 
           UCS2114_REG_PORT2_CURRENT_LIMIT_BEHAVIOR, iLimBehP2.byte_val);      
}


bool UCS2114_is_connected(void)
{
    I2C_master_read_one_byte_register(UCS2114_ADDRESS ,UCS2114_REG_PRODUCT_ID);
            
    if (I2C_master_read_one_byte_register(UCS2114_ADDRESS ,UCS2114_REG_PRODUCT_ID) 
            != UCS2114_PRODUCT_ID_VAL)
    {
        return false; // false means that the slave is not UCS2114
    }       
    return true;  // Connection ok
}


void UCS2114initialize(void)
{

    //general configuration 2 register
    //b7 - alert_2mask - alert only on ov_lim2 and over temp
    //b6 - unimplemented
    //b5 - dschrg2 - port 2 not in discharge
    //b4 - pwr_en2s - port power enable override not used
    //b3-2 - dischr_time - 400ms
    //b1-0 - unimplemented
    //0b1-001100 = 0x8C
    genConfig2.byte_val = 0x8C;
    I2C_master_write_one_byte_register(UCS2114_ADDRESS, 
           UCS2114_REG_GENERAL_CONFIGURATION2, 0x8C); 
    
    //general configuration 1 register
    //b7 - alert_1mask - alert only on ov_lim1 and over temp
    //b6 - unimplemented
    //b5 - dschrg1 - port 2 not in discharge
    //b4 - pwr_en21 - port power enable override not used
    //b3 - unimplemented
    //b2 - en_vbus_dischg - disabled
    //b1-0 - unimplemented
    //0b1-000000 = 0x80
    genConfig1.byte_val = 0x80;
    I2C_master_write_one_byte_register(UCS2114_ADDRESS, 
           UCS2114_REG_GENERAL_CONFIGURATION1, 0x80);
    
    //general configuration 3 register
    //b7 - pin_ign - dont ignore pwr pins for pwr state
    //b6 - reserved - 1
    //b5 - dis_to - disable smbus timeout
    //b4-3 - unimplemented
    //b2 - boost - disabled
    //b1-0 - unimplemented
    //0b01100000 = 0x60
    genConfig3.byte_val = 0x60;
    I2C_master_write_one_byte_register(UCS2114_ADDRESS, 
           UCS2114_REG_GENERAL_CONFIGURATION3, 0x60);
    
    //current limit register
    //3.2A for both ports
    //b7-6 - unimplemented
    //b5-3 - 3.2A
    //b2-0 - 3.2A
    //0b00111111 = 0x3F
    I2C_master_write_one_byte_register(UCS2114_ADDRESS, 
           UCS2114_REG_CURRENT_LIMIT, 0x3F);
    
    //auto recovery register
    //left at power-up defaults
    I2C_master_write_one_byte_register(UCS2114_ADDRESS, 
           UCS2114_REG_AUTO_RECOVERY_CONFIGURATION, 0x2A);

    //port charge rationing threshold registers all left at power on defaults
    I2C_master_write_one_byte_register(UCS2114_ADDRESS, 
           UCS2114_REG_PORT1_CHARGE_RATIONING_THRESHOLD_HIGH_BYTE, 0xFF);
    I2C_master_write_one_byte_register(UCS2114_ADDRESS, 
           UCS2114_REG_PORT1_CHARGE_RATIONING_THRESHOLD_LOW_BYTE, 0xFF);
    I2C_master_write_one_byte_register(UCS2114_ADDRESS, 
           UCS2114_REG_PORT2_CHARGE_RATIONING_THRESHOLD_HIGH_BYTE, 0xFF);
    I2C_master_write_one_byte_register(UCS2114_ADDRESS, 
           UCS2114_REG_PORT2_CHARGE_RATIONING_THRESHOLD_LOW_BYTE, 0xFF);
    
    //charge rationing left at default - off
    I2C_master_write_one_byte_register(UCS2114_ADDRESS, 
           UCS2114_REG_RATION_CONFIGURATION, 0x11);
    
    //current limit behaviour for port 1 and 2 defaults
    iLimBehP2.byte_val = 0x96;
    iLimBehP1.byte_val = 0x96;
    I2C_master_write_one_byte_register(UCS2114_ADDRESS, 
           UCS2114_REG_PORT1_CURRENT_LIMIT_BEHAVIOR, 0x96);
    I2C_master_write_one_byte_register(UCS2114_ADDRESS, 
           UCS2114_REG_PORT2_CURRENT_LIMIT_BEHAVIOR, 0x96);
}

uint8_t UCS2114_get_port_one_current(void)
{
    return I2C_master_read_one_byte_register(UCS2114_ADDRESS,
            UCS2114_REG_PORT1_CURRENT_MEASUREMENT);
}

uint8_t UCS2114_get_port_two_current(void)
{
    return I2C_master_read_one_byte_register(UCS2114_ADDRESS,
            UCS2114_REG_PORT2_CURRENT_MEASUREMENT);
}
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

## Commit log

2020-07-19 Initial open sourcing of SBC²
    [4 port powered backplane.brd, 4 port powered backplane.sch]
2020-10-27 Initial frontend
    power monitoring working
    [appconfig.cfg]
2020-10-28 Added ability to hard reset each slot
    fixed slot 2 displaying slot 1 current
    [routes.py, usbhubinterface.py]
2020-11-08 Fixed firmware update; Fixed occasional conflict between bootloader and program I2C comms
    [I2C_Slave_Interrupt_Handlers.c, hubinterface.py, routes.py]
2020-12-13 Added case designs
2021-01-20 removed errant wiringpi in requirements.txt
